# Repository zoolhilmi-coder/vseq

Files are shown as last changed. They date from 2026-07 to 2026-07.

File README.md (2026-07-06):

# VSeq — Voltage Sequence Analyzer

Multi-channel voltage monitor dengan paparan ala logic analyzer / oscilloscope. Sesuai untuk debug power sequencing pada GPU, motherboard, atau mana-mana PCB.

---

## 🖥️ PC Software (Guna Sekarang — Tanpa Hardware)

### Demo Mode
```
Buka index.html dalam Chrome atau Edge
→ Demo Mode auto-start — akan simulate GPU power sequence
```

**Requirements:**  
Chrome 89+ atau Edge 89+ (untuk Web Serial API)

### Features
| Feature | Cara Guna |
|---|---|
| **Zoom** | Scroll mouse pada waveform |
| **Pan** | Drag kiri-kanan |
| **Follow latest** | Double-click atau klik ⟫ Follow |
| **Cursor** | Right-click letak cursor (C1/C2) |
| **Tooltip** | Hover untuk baca nilai semua channel |
| **Trigger** | Set channel + threshold + ARM |
| **Rename channel** | Double-click nama channel di sidebar |
| **Hide/show** | Klik 👁 pada channel |
| **Export PNG** | Toolbar → PNG |
| **Export CSV** | Toolbar → CSV |

---

## ⚡ Hardware — RP2040 (Raspberry Pi Pico)

### Bill of Materials

| Qty | Part | Value | Notes |
|-----|---|---|---|
| 1 | Raspberry Pi Pico | — | RP2040, USB built-in |
| 2 | MCP3204-CI/P | 12-bit ADC | SPI, 4ch each |
| 10 | Resistor | 100Ω | Input series resistor |
| 10 | Zener diode | 3.3V | Input clamp protection |
| 10 | Test probe / pogo pin | — | For probing PCB |
| Varies | Voltage divider R | See table | Scale high voltages |

### Voltage Divider Values per Rail

| Rail | Voltage | R1 | R2 | Scale |
|---|---|----|----|---|
| 12V  | 12V | 39kΩ | 12kΩ | 4.25x |
| 5V | 5V  | 20kΩ | 22kΩ | 1.91x |
| 3.3V | 3.3V | Direct | — | 1.0x |
| EN, VCORE, VRAM, etc. | ≤3.3V | Direct | — | 1.0x |

> **⚠️ Warning:** Jangan probe mana-mana voltage melebihi 3.3V tanpa voltage divider + Zener clamp. RP2040 ADC toleran max 3.3V.

---

## 🔌 Wiring Diagram

```
Pico GPIO   Function
─────────────────────────────────────────
GP26  ──►  CH0 ADC input  (internal ADC0)
GP27  ──►  CH1 ADC input  (internal ADC1)
GP28  ──►  CH2 ADC input  (internal ADC2)

GP2   ──►  SPI0 SCK  (MCP3204 A & B)
GP3   ──►  SPI0 MOSI (MCP3204 A & B)
GP4   ──►  SPI0 MISO (MCP3204 A & B)
GP5   ──►  CS_A (MCP3204 A → CH3–CH6)
GP9   ──►  CS_B (MCP3204 B → CH7–CH9)

3V3   ──►  VDD  (MCP3204 power + VREF)
GND   ──►  VSS  (common ground)
VBUS  ──►  USB  (PC connection)
```

### MCP3204 Pinout (each chip)

```
MCP3204 A (CH3–CH6):
  CH0/IN0 → Probe CH3
  CH1/IN1 → Probe CH4
  CH2/IN2 → Probe CH5
  CH3/IN3 → Probe CH6

MCP3204 B (CH7–CH9):
  CH0/IN0 → Probe CH7
  CH1/IN1 → Probe CH8
  CH2/IN2 → Probe CH9
  CH3/IN3 → (spare / GND)
```

### Per-channel input circuit

```
Probe tip
   │
  [100Ω]    ← Series protection resistor
   │
   ├──[Zener 3.3V]── GND  ← Clamp overvoltage
   │
  [R1]      ← Voltage divider (for >3.3V rails)
   │
  [R2]      ← To GND
   │
  ADC pin
```

---

## 💾 Flash Firmware

1. Download **MicroPython UF2** dari [micropython.org/download/rp2-pico](https://micropython.org/download/rp2-pico/)
2. Hold BOOTSEL → plug USB → release
3. Drag UF2 ke drive `RPI-RP2`
4. Copy `firmware/main.py` ke Pico menggunakan **Thonny** atau **rshell**:

```bash
# Via rshell
pip install rshell
rshell --port /dev/tty.usbmodem* cp firmware/main.py /pyboard/main.py
```

5. Reset Pico
6. Buka VSeq PC app → **Connect USB** → pilih port Pico

---

## 📡 Serial Protocol

```
# PC → Pico (commands)
START           Start streaming data
STOP            Stop streaming
RATE:1000       Set sample rate (Sa/s), max 5000
ID?             Query device identity

# Pico → PC (data)
# VSeq v1.0 RP2040 10ch         (startup message)
1234.500,12.003,4.998,...       (CSV: time_ms, v0..v9)
```

---

## 📊 Performance

| Parameter | Value |
|---|---|
| ADC resolution | 12-bit (4096 steps) |
| Voltage resolution | ~0.8 mV @ 3.3V |
| Max sample rate | ~5 kSa/s (shared, USB bandwidth limited) |
| Channels | 10 (3 internal + 7 via SPI ADC) |
| Input range | 0–3.3V (hardware protected) |
| Supported rails | Up to 12V (with divider) |
| USB mode | CDC Serial — no driver needed |

---

## 🔧 Troubleshooting

**"No data" in app:**
- Pastikan klik **▶ Capture** lepas connect
- Check baud rate: 921600 bps

**Noisy readings:**
- Tambah 100nF ceramic cap antara ADC pin dan GND
- Pastikan ground probe disambung ke PCB GND yang sama

**Wrong voltage reading:**
- Semak `SCALE_FACTORS` dalam `firmware/main.py`
- Match dengan voltage divider yang kau guna

---

## 📁 Project Structure

```
vseq/
├── index.html          ← PC Web App
├── style.css           ← Dark oscilloscope theme
├── js/
│   ├── app.js          ← Main orchestrator
│   ├── renderer.js     ← Canvas waveform engine
│   ├── serial.js       ← Web Serial API wrapper
│   └── demo.js         ← GPU power sequence simulator
├── firmware/
│   └── main.py         ← MicroPython for RP2040
└── README.md           ← This file
```

---

*VSeq — Built for hardware engineers who want a real-time, multi-channel voltage view without a RM3000 scope.*

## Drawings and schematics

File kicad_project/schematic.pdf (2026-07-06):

# VSeq — FULL 10-CHANNEL HARDWARE SCHEMATIC (STM32 VERSION)

Input Range: -30V to +30V (Every Channel) | | Input Impedance: 1M Ohm | | Op-Amp Active Overvoltage Protection Clamp

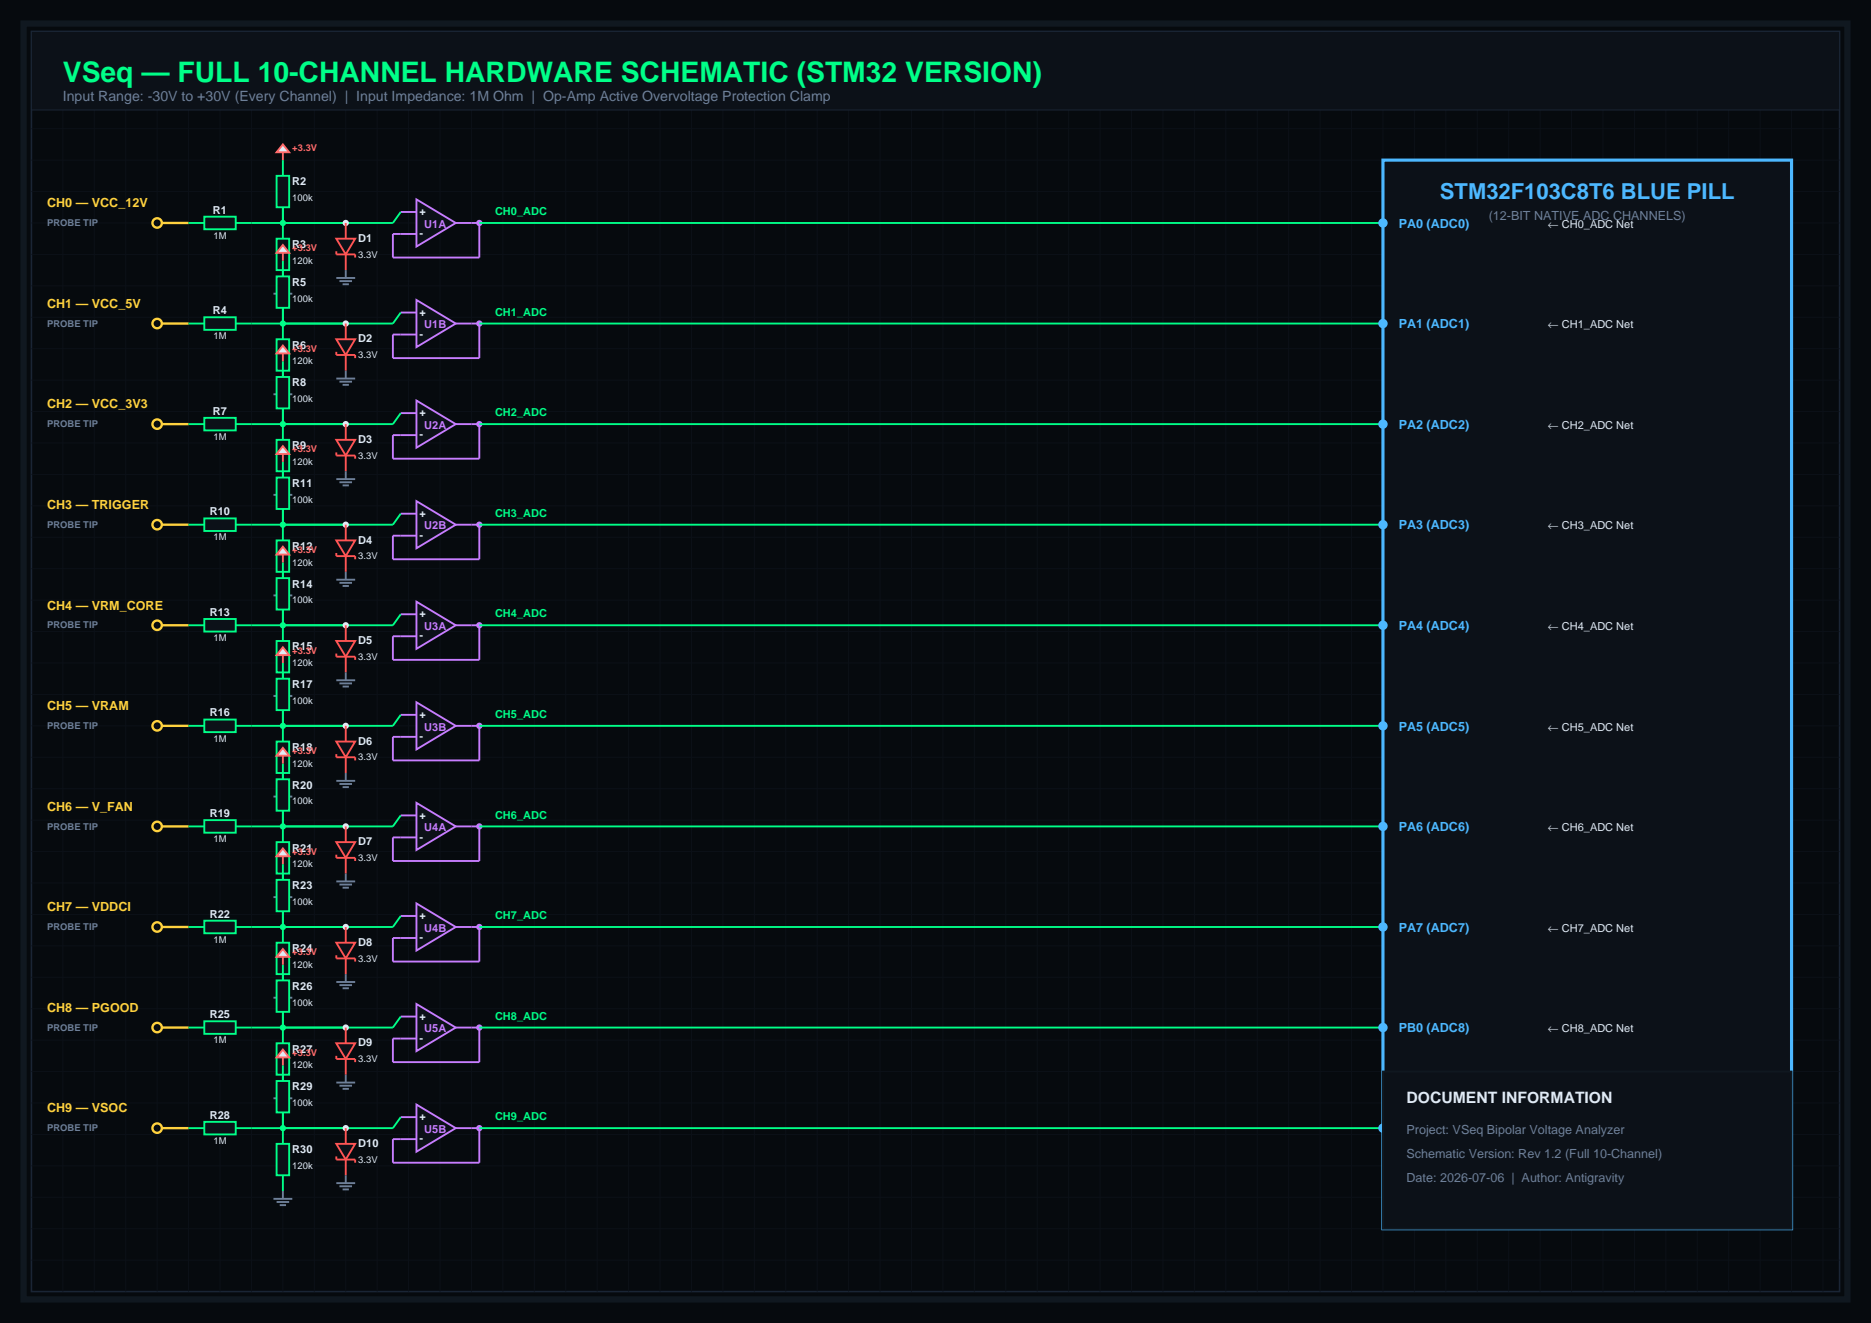
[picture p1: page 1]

(12-BIT NATIVE ADC CHANNELS)

Project: VSeq Bipolar Voltage Analyzer
Schematic Version: Rev 1.2 (Full 10-Channel)

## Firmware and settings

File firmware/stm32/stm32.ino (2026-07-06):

/*
  VSeq Firmware — STM32 (stm32.ino)
  Written for Arduino IDE with STM32 Cores (STM32duino)
  Compatible with STM32F103C8T6 (Blue Pill), STM32F401, STM32F411, etc.
  
  Reads 10 internal ADC channels directly and streams voltage data over USB CDC Serial.
  This avoids the need for external SPI ADC chips (MCP3204/8) since STM32 has 10+ ADC pins.
  
  Default Pin mapping on STM32F103C8T6 (Blue Pill):
    - CH0: PA0 (A0) - VCC_12V (Requires Voltage Divider)
    - CH1: PA1 (A1) - VCC_5V  (Requires Voltage Divider)
    - CH2: PA2 (A2) - VCC_3V3 (Direct / Divider)
    - CH3: PA3 (A3) - TRIGGER (Direct / Divider)
    - CH4: PA4 (A4) - VRM_CORE
    - CH5: PA5 (A5) - VRAM
    - CH6: PA6 (A6) - V_FAN   (Requires Voltage Divider)
    - CH7: PA7 (A7) - VDDCI
    - CH8: PB0 (A8) - PGOOD
    - CH9: PB1 (A9) - VSOC
    
  ⚠️ WARNING: All input voltages exceeding 3.3V MUST use voltage dividers.
*/

#include <Arduino.h>

#define BAUD_RATE 921600
#define ADC_RESOLUTION 12 // 12-bit ADC (0 - 4095)
#define VREF 3.3f

// Pin mapping for 10 ADC channels
const int ADC_PINS[10] = {
  PA0, // CH0 - A0 (VCC_12V via divider)
  PA1, // CH1 - A1 (VCC_5V via divider)
  PA2, // CH2 - A2 (VCC_3V3 direct)
  PA3, // CH3 - A3 (TRIGGER direct)
  PA4, // CH4 - A4 (VRM_CORE direct)
  PA5, // CH5 - A5 (VRAM direct)
  PA6, // CH6 - A6 (V_FAN via divider)
  PA7, // CH7 - A7 (VDDCI direct)
  PB0, // CH8 - A8 (PGOOD direct)
  PB1  // CH9 - A9 (VSOC direct)
};

// Voltage mapping coefficients for y = m * x + c (to map -30V..+30V input to 0..3.3V ADC pin)
// With E12 resistors: R1 (Input) = 100k, R2 (Bias to 3.3V) = 10k, R3 (to GND) = 12k
// Vin = Vx * (1 + R1/R2 + R1/R3) - V_BIAS * (R1/R2)
// Vin = Vx * 19.3333f - 33.0f
const float CAL_M[10] = {19.3333f, 19.3333f, 19.3333f, 19.3333f, 19.3333f, 19.3333f, 19.3333f, 19.3333f, 19.3333f, 19.3333f};
const float CAL_C[10] = {-33.0000f, -33.0000f, -33.0000f, -33.0000f, -33.0000f, -33.0000f, -33.0000f, -33.0000f, -33.0000f, -33.0000f};

bool running = false;
unsigned long sampleIntervalUs = 1000; // default 1000us (1kHz)
unsigned long nextSampleUs = 0;
unsigned long t0_ms = 0;

void handleCommand(String cmd) {
  cmd.trim();
  if (cmd == "START") {
    running = true;
    t0_ms = millis();
    nextSampleUs = micros();
  } else if (cmd == "STOP") {
    running = false;
  } else if (cmd.startsWith("RATE:")) {
    long hz = cmd.substring(5).toInt();
    if (hz > 0) {
      sampleIntervalUs = 1000000 / min(5000L, max(1L, hz));
    }
  } else if (cmd == "ID?") {
    Serial.println("# VSeq v1.0 STM32 10ch");
  }
}

void setup() {
  // Initialize USB Serial (CDC)
  Serial.begin(BAUD_RATE);
  
  // Set ADC resolution (12-bit is native for STM32)
  analogReadResolution(ADC_RESOLUTION);
  
  // Configure analog pins as analog inputs
  for (int i = 0; i < 10; i++) {
    pinMode(ADC_PINS[i], INPUT_ANALOG);
  }
}

void loop() {
  // Read incoming serial commands
  if (Serial.available() > 0) {
    String cmd = Serial.readStringUntil('\n');
    handleCommand(cmd);
  }

  if (!running) {
    delay(10);
    return;
  }

  // Rate-limited sampling
  unsigned long now = micros();
  if (now >= nextSampleUs) {
    nextSampleUs += sampleIntervalUs;
    
    float t_ms = (float)(millis() - t0_ms);
    
    // Print timestamp
    Serial.print(t_ms, 3);
    
    // Read and print each channel
    for (int i = 0; i < 10; i++) {
      int raw = analogRead(ADC_PINS[i]);
      float vx = ((float)raw / 4095.0f) * VREF;
      float voltage = vx * CAL_M[i] + CAL_C[i];
      Serial.print(",");
      Serial.print(voltage, 4);
    }
    Serial.println();
  }
}

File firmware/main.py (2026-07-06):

"""
VSeq Firmware — main.py
Raspberry Pi Pico (RP2040) / MicroPython

Reads 10 ADC channels and streams voltage data over USB serial.
- CH0–CH2 : RP2040 built-in ADC (GP26, GP27, GP28) — 0-3.3V
- CH3–CH9 : Two MCP3204 chips via SPI (4 ch each) — 0-3.3V

Data line format (one line per sample set):
  "<timestamp_ms>,<v0>,<v1>,...,<v9>\n"
  e.g. "1234.500,12.003,4.998,3.301,1.800,1.000,1.351,0.900,1.800,3.298,0.751"

Voltage divider ratios per channel are configured here.
For channels probing >3.3V rails, set SCALE_FACTOR accordingly.
"""

import machine
import utime
import sys

# ─── Configuration ─────────────────────────────────────────
BAUD_RATE    = 921600
SAMPLE_RATE  = 1000    # Hz — samples per second per channel

# Voltage scale factors (hardware voltage divider ratios)
# e.g. 12V rail: R1=39k, R2=12k → ratio = (39+12)/12 = 4.25
SCALE_FACTORS = [
    4.25,   # CH0 — 12V  rail  (R:39k/12k)
    1.65,   # CH1 — 5V   rail  (R:20k/22k)
    1.0,    # CH2 — 3.3V rail  (direct)
    1.0,    # CH3 — EN   signal (direct ≤3.3V)
    1.0,    # CH4 — VCORE      (direct ≤3.3V)
    1.0,    # CH5 — VRAM       (direct ≤3.3V)
    1.0,    # CH6 — VDDCI      (direct ≤3.3V)
    1.0,    # CH7 — MVDD       (direct ≤3.3V)
    1.0,    # CH8 — PGOOD      (direct ≤3.3V)
    1.0,    # CH9 — VSOC       (direct ≤3.3V)
]

ADC_VREF = 3.3    # Reference voltage
ADC_BITS = 12     # MCP3204 is 12-bit; RP2040 ADC is 12-bit effective

# ─── SPI / MCP3204 setup ────────────────────────────────────
# MCP3204A: channels 3–6  (CS = GP5)
# MCP3204B: channels 7–9  (CS = GP9) — only 3 of 4 used
SPI_ID   = 0
SPI_SCK  = machine.Pin(2)
SPI_MOSI = machine.Pin(3)
SPI_MISO = machine.Pin(4)
CS_A     = machine.Pin(5,  machine.Pin.OUT, value=1)
CS_B     = machine.Pin(9,  machine.Pin.OUT, value=1)

spi = machine.SPI(SPI_ID,
                  baudrate=1_000_000,
                  polarity=0,
                  phase=0,
                  bits=8,
                  sck=SPI_SCK,
                  mosi=SPI_MOSI,
                  miso=SPI_MISO)

# ─── Internal ADC (CH0–CH2) ──────────────────────────────────
adc0 = machine.ADC(machine.Pin(26))   # CH0
adc1 = machine.ADC(machine.Pin(27))   # CH1
adc2 = machine.ADC(machine.Pin(28))   # CH2
internal_adcs = [adc0, adc1, adc2]

# ─── MCP3204 read ────────────────────────────────────────────
def mcp3204_read(cs_pin, channel):
    """Read one channel (0-3) from MCP3204.  Returns 12-bit integer."""
    # Start bit + SGL/DIFF (1=single) + D2 + D1 + D0
    start   = 0b00000110  | ((channel >> 2) & 1)
    cfg     = (channel & 0x03) << 6
    buf_tx  = bytearray([start, cfg, 0x00])
    buf_rx  = bytearray(3)
    cs_pin.value(0)
    spi.write_readinto(buf_tx, buf_rx)
    cs_pin.value(1)
    return ((buf_rx[1] & 0x0F) << 8) | buf_rx[2]

def read_all_channels():
    """Return list of 10 voltages (float, V)."""
    readings = []
    # Internal ADC: CH0–CH2
    for adc in internal_adcs:
        raw = adc.read_u16() >> 4   # 16-bit → 12-bit
        v   = (raw / 4095.0) * ADC_VREF
        readings.append(v)
    # MCP3204 A: CH3–CH6
    for ch in range(4):
        raw = mcp3204_read(CS_A, ch)
        v   = (raw / 4095.0) * ADC_VREF
        readings.append(v)
    # MCP3204 B: CH7–CH9
    for ch in range(3):
        raw = mcp3204_read(CS_B, ch)
        v   = (raw / 4095.0) * ADC_VREF
        readings.append(v)
    # Apply scale factors
    return [readings[i] * SCALE_FACTORS[i] for i in range(10)]

# ─── Command parser ───────────────────────────────────────────
running    = False
sample_us  = 1_000_000 // SAMPLE_RATE   # microseconds per sample
t0_ms      = utime.ticks_ms()

def handle_command(cmd):
    global running, sample_us
    cmd = cmd.strip()
    if cmd == 'START':
        running = True
    elif cmd == 'STOP':
        running = False
    elif cmd.startswith('RATE:'):
        try:
            hz = int(cmd[5:])
            sample_us = 1_000_000 // max(1, min(5000, hz))
        except:
            pass
    elif cmd == 'ID?':
        sys.stdout.write('# VSeq v1.0 RP2040 10ch\n')

# ─── Main loop ───────────────────────────────────────────────
print('# VSeq v1.0 — send START to begin\n')

buf_in = ''
next_t = utime.ticks_us()

while True:
    # Non-blocking command read
    try:
        while sys.stdin.readable():   # type: ignore[attr-defined]
            ch = sys.stdin.read(1)
            if not ch:
                break
            buf_in += ch
            if '\n' in buf_in:
                line, buf_in = buf_in.split('\n', 1)
                handle_command(line)
    except:
        pass

    if not running:
        utime.sleep_ms(10)
        continue

    # Rate-limited sampling
    now = utime.ticks_us()
    if utime.ticks_diff(next_t, now) > 0:
        utime.sleep_us(utime.ticks_diff(next_t, now))
    next_t = utime.ticks_add(now, sample_us)

    t_ms    = utime.ticks_diff(utime.ticks_ms(), t0_ms)
    voltages = read_all_channels()

    # Format: "timestamp_ms,v0,v1,...,v9\n"
    line = '{:.3f},{}\n'.format(
        t_ms,
        ','.join('{:.4f}'.format(v) for v in voltages)
    )
    sys.stdout.write(line)

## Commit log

2026-07-06 initial: 10-ch voltage sequence analyzer app & firmware
2026-07-06 added voltage pinning (annotations) on quick click and auto-zoom to 70% width on selection
2026-07-06 added STM32 Arduino C++ firmware
2026-07-06 added vector schematic PDF and generator script
2026-07-06 updated stm32 firmware, web app default channel configuration, and schematic pdf to support bipolar -30V to +30V range on every channel
2026-07-06 added active Op-Amp voltage buffer and updated 1M/100k/120k resistors for high impedance -30V to +30V level shifter input stage
2026-07-06 added complete KiCad CAD project including schematic with PCB net labels and board file
    [vseq.kicad_pcb, vseq.kicad_sch]
2026-07-06 embedded download links for KiCad CAD ZIP and Schematic PDF in app toolbar
2026-07-06 updated generate_schematic.py to render full 10-channel schematic PDF and updated kicad_project.zip to include it
2026-07-06 Fix KiCad schematic root token from kicad_schematic to kicad_sch and update zip
    [vseq.kicad_pcb, vseq.kicad_sch]
2026-07-06 Remove invalid (pin_numbers write_pin_numbers) syntax from KiCad symbols
    [vseq.kicad_pcb, vseq.kicad_sch]
2026-07-06 Ensure schematic.pdf is present and updated
    [vseq.kicad_pcb, vseq.kicad_sch]
2026-07-06 Fix polyline symbol graphics syntax from invalid nested polyline to standard (pts (xy ...))
    [vseq.kicad_pcb, vseq.kicad_sch]
2026-07-06 Remove invalid (stroke ...) property from junction elements
    [vseq.kicad_pcb, vseq.kicad_sch]
2026-07-06 Fix KiCad PCB file format by removing root uuid tag and adding required layers
    [vseq.kicad_pcb, vseq.kicad_sch]
2026-07-07 Complete rewrite: KiCad 7 valid schematic with TLV2371 op-amp buffer, correct polyline/pin syntax, valid PCB
    [vseq.kicad_pcb, vseq.kicad_sch]
2026-07-07 Fix: remove invalid landscape keyword from paper tag (KiCad only accepts portrait or nothing)
    [vseq.kicad_sch]
2026-07-07 Fix: remove net_tie and smd_soldermask_margin, add proper global_label property, strip PCB setup to minimum
    [vseq.kicad_pcb, vseq.kicad_sch]
2026-07-07 Add kicad-cli upgrade pipeline: auto-convert to KiCad 10 format after generation
    [vseq.kicad_sch]
